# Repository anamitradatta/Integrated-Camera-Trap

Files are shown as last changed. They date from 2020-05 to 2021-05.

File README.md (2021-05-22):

Integrated-Camera-Trap

Senior Design Project 2020 Team 15

Members: <br />
Anamitra Datta  <br />
Max Haimowitz <br />
Xiaoyang Pan <br />
Minting Chen <br />

Advisors: <br />
Professor Duncan Irschick: (https://www.bio.umass.edu/biology/about/directories/faculty/duncan-j-irschick) <br />
Professor David Schmidt: (https://mie.umass.edu/faculty/david-schmidt) <br />
Professor Marco Duarte (ECE SDP Advisor) : (https://ece.umass.edu/faculty/marco-duarte) <br />

http://www.ecs.umass.edu/ece/sdp/sdp20/team15/

Network of Raspberry Pis connected with Camera Modules to take synchronized pictures via WIFI using Message Query Telemetry Transport (MQTT) (Mosquitto) triggered by motion sensors

If you need access to this repository, contact me at my email address: anamitradatta@gmail.com and cc Professor Duncan 
Irschick and/or Professor David Schmidt and ask them to grant permission. Please provide your github username as well.

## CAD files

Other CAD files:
3d_models/SensorShell.f3d
3d_models/enclosure.f3d

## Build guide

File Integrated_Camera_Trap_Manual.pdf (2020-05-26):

# Integrated Camera Trap

## Installation Guide and Instruction Manual

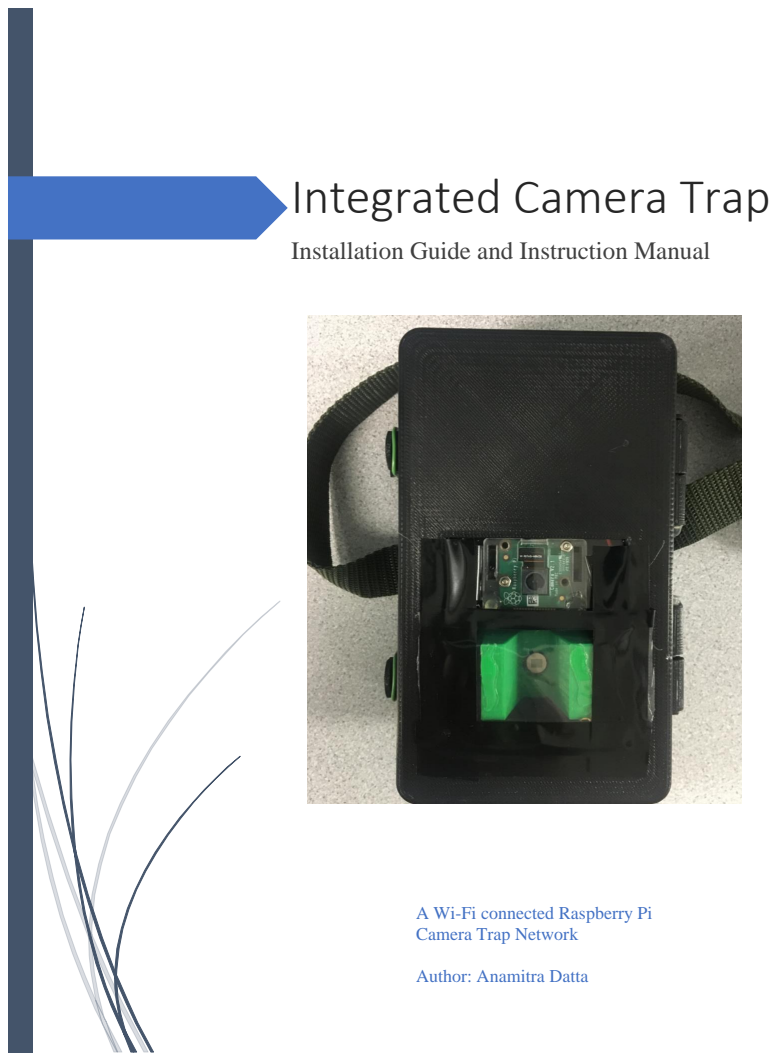
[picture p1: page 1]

A Wi-Fi connected Raspberry Pi
Camera Trap Network

Author: Anamitra Datta

## Contents

## 1. Introduction

### a. Background

Camera Traps have been used by biologists and wildlife researchers to observe animals through the use of photos and 3D modeling rather than dangerous and disruptive physical techniques such as tranquilization and traps which can disturb and harm animals. However, the problem with current camera traps is that they are neither connected nor synchronized. This becomes an issue when photo sets generated by the camera traps are used for 3D modeling, resulting in poor, disconnected, and fragmented models as a result of desynchronized photos. Our system aims to improve this issue by connecting the camera traps through Wi-Fi and ensuring photo capturing synchronization through timed messages sent over Wi-Fi, telling each camera trap when to take a photo.

### b. Network Design

Our network uses a master-slave paradigm in which one “master”/main device sends messages to all the of the “slave”/secondary devices when to take a photo. The figure below shows how to the system is set up.

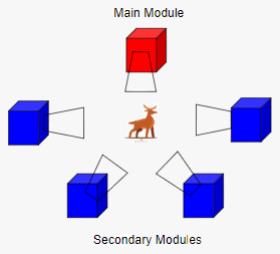
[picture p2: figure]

The camera traps should be arranged in a circle around a single point/area of focus where an animal is likely to appear. There should only be one “master” device in the network and the rest of the devices should be “slave” devices.

### c. Hardware

Our camera trap runs on a Raspberry Pi Zero WH (Wireless with Headers) as shown below

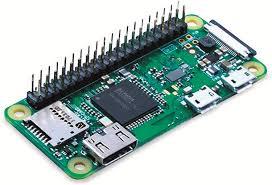
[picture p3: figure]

A Raspberry Pi is a small single-board computer. This board functions like a normal computer in which you can run software and even install physical components.

More information about the Raspberry Pi can be found on the official Raspberry Pi website: https://www.raspberrypi.org/

### d. Software and Networking

The system runs on Wi-Fi through the use of either a router or a wireless access point that can be set up using a Raspberry Pi.

The messages sent within the system are through the use of MQTT (Message Queuing Telemetry Transport). A “broker” is used to send or “publish” messages to all devices listening or “subscribing” to an MQTT “topic” or channel within a network. The broker/publisher and subscribers can be set up using Mosquitto, a free, open-source software for MQTT. More information about Mosquitto can be found on the official Mosquitto website: https://mosquitto.org/

The code running the camera synchronization and photo capturing script is written in Python. More information about Python can be found on the official Python website: https://www.python.org/

## 2. Unix

### a. Introduction to Unix

The Raspbian OS that the Raspberry Pi uses is part of the Linux/Unix OS family. Knowledge of this OS and how to use it is necessary for this system. This chapter covers all of the basic topics of the Raspbian OS that are needed for this system to function.

### b. Basic commands

The main way people use a Linux/Unix based operating system is through the command line or terminal. In this section we will cover some basic command line functions so you can get used to working in a Linux/Unix environment. Documentation for Linux commands: http://man7.org/linux/man-pages/index.html . Also type “man <command name>” to get information about a particular Linux command.

i. ls
This lists the contents of the directory you are currently in or the directory you specify

ii. cd
This changes the directory you are currently in. If you want to change to a different directory type this command.

iii. mv
Move a file to a destination directory optionally with a different name and delete the old file.

iv. cp
Copy a file to a destination directory optionally with a different name and preserve the old file.
v. rm
Remove a file or directory

vi. mkdir
Make a directory

vii. pwd
Print the current working directory you are in.

Permissions
Permissions control who can read, write, or execute a file or directory. Root has the highest permission in Unix subsystems. To be a root user, you must in the sudoers list in the operating system (you are automatically in it by default on Raspbian). Next you must type in the command “sudo su” to change to the root user. Sometimes you need a password to become the root user. If you ever need root privilege to execute a command type “sudo” before your whole command.

viii. chmod
Change read, write, and execute permissions of a file.

ix. chown
Change who owns a file or directory.

### c. Processes

Programs and other software that run on an Operating System are referred to as processes. When you execute a program or command, it will run as a process. Here are commands that deal with processes:

i. ps
Lets you view all process running on the operating system. Alternatives include top or htop

ii. kill
Kill or stop a process from executing

### d. Power

i. reboot
Restart/reboot the Pi

ii. poweroff
Shutdown the Pi.

### e. Startup services

In our system, we have programs that must start up immediately when the Raspberry Pi boots up. There are many different ways to start programs up on boot.

i. rc.local
This is a file that starts just after all normal services have been started. This is just a bash script file which can run shell commands or any software commands. It is located in the /etc/ folder.

For example, we can start the mobile app with the command “python -u ct_mobile_server.py > output.txt 2>error.txt </dev/null &” and put it in the rc.local file. This starts the mobile app server as a background process and writes the output and errors to separate files on startup, as long as it connected to a proper Wi-Fi network.

ii. Systemd
https://www.freedesktop.org/wiki/Software/systemd/

https://www.raspberrypi-spy.co.uk/2015/10/how-to-autorun-a-python-script-on-boot-using-systemd/ (https://www.raspberrypi-spy.co.uk/2015/10/how-to-autorun-a-python-script-on-boot-using-systemd/)

Systemd is a service manager which can control which process can run on startup and run them as a service file.

To set a python program (for example, the CT slave program) as a systemd service, write the service file with the command “sudo nano /lib/systemd/ctslave.service”

Add in the following to the ctslave.service file and save it:
[Unit]
Description=Camera Trap Slave Service After=network-online.target Wants=network-online.target

[Service]
Type=idle
User=pi
ExecStart=python -u /home/pi/ct_client_slave.py

[Install]
WantedBy=network-online.target

Give the file root permissions with the command “sudo chmod 777 /lib/systemd/ctslave.service” Type in the commands “sudo systemctl daemon-reload” and “sudo systemctl enable ctslave.service” and then reboot the pi. The program should successfully run on startup. You can check using “sudo systemctl status ctslave.service” . You can check the output of the service using journalctl.

You can start the mobile app server or the slave or master CT programs using systemd

iii. Cron
http://man7.org/linux/man-pages/man5/crontab.5.html

Cron is a software utility which provides a time based job scheduler. You can start scripts or programs at specific times. Here is a guide on how to write a crontab to automatically start a program or command: https://help.ubuntu.com/community/CronHowto

## 3. Installation and Setup

### Camera Trap Raspberry Pi a. Supplies

The supplies we used are listed below, but you can use any components that are similar and fit within the enclosure

PIR Motion Sensor | Adafruit | HC-SR501 | $10.00
Raspberry Pi Zero WH | Raspberry Pi | Zero WH | $14.00
Raspberry Pi Camera Module V2 (8 Megapixel,1080p) | Raspberry Pi | V2, 8MP, 1080p | ~$25.00

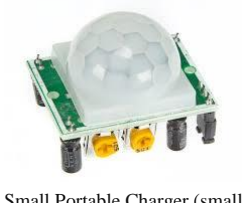
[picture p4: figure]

Portable Charger | Sethruki | 20000mAh, T-28 | ~$25.00
Raspberry Pi Zero WH (Wireless With Headers) | HC-SR501 PIR Motion Sensor

Small Portable Charger (small

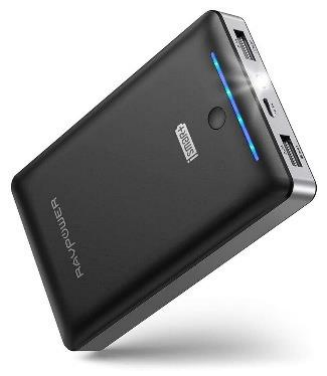
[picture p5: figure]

enough to fit in enclosure)

MicroSD card (16-32 GB) and SD Card Adapter | Micro USB to USB adapter or

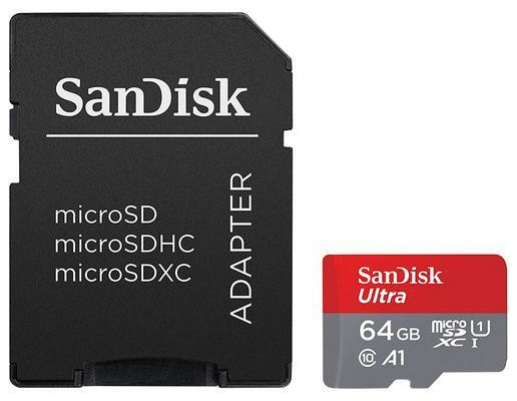
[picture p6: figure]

| USB Hub (for USB Wireless Mouse and Keyboard)

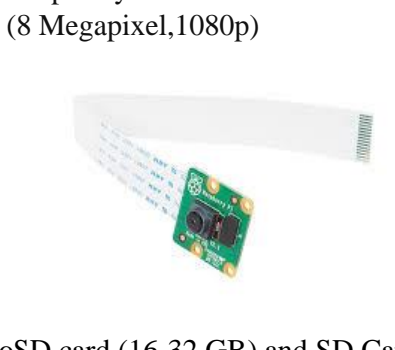
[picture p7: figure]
(8 Megapixel,1080p)

Raspberry Pi Camera Module V2

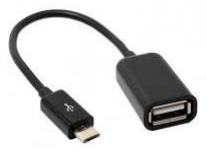
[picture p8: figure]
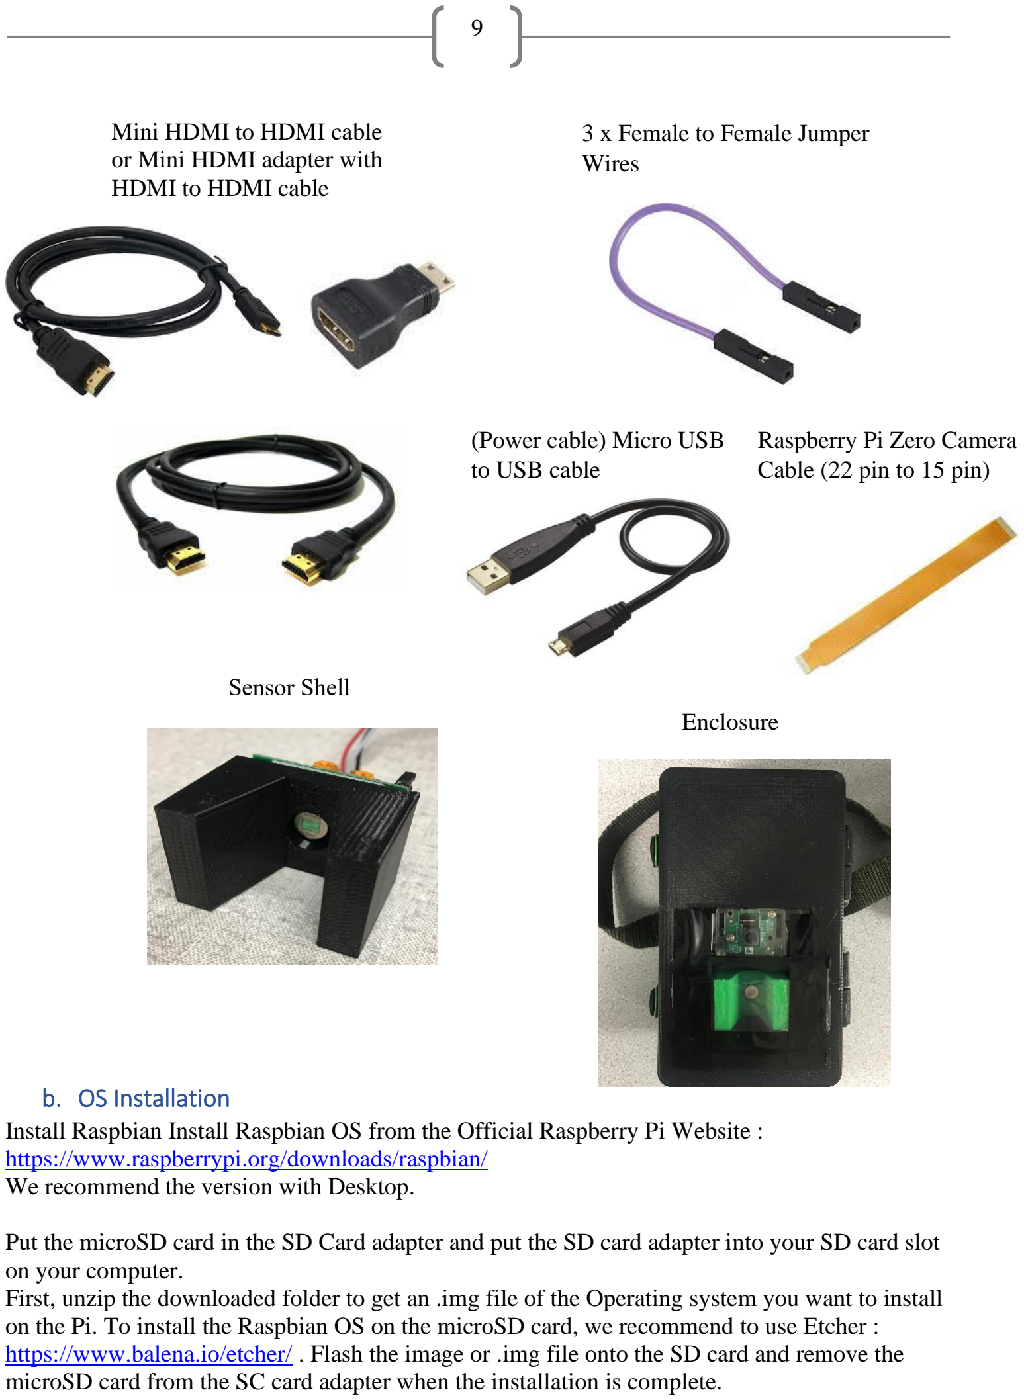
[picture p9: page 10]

### b. OS Installation

Install Raspbian Install Raspbian OS from the Official Raspberry Pi Website : https://www.raspberrypi.org/downloads/raspbian/
We recommend the version with Desktop.

Put the microSD card in the SD Card adapter and put the SD card adapter into your SD card slot on your computer.
First, unzip the downloaded folder to get an .img file of the Operating system you want to install on the Pi. To install the Raspbian OS on the microSD card, we recommend to use Etcher : https://www.balena.io/etcher/ . Flash the image or .img file onto the SD card and remove the microSD card from the SC card adapter when the installation is complete.

Mini HDMI to HDMI cable
or Mini HDMI adapter with
HDMI to HDMI cable

3 x Female to Female Jumper Wires

(Power cable) Micro USB
to USB cable

Raspberry Pi Zero Camera
Cable (22 pin to 15 pin)

Sensor Shell
Enclosure

### c. Setting up the Raspberry Pi

i. Add components and start up OS

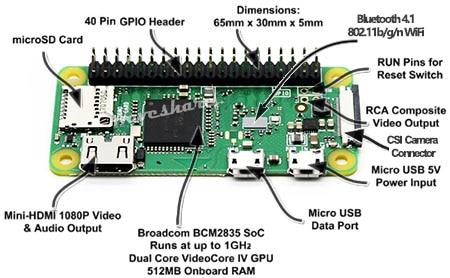
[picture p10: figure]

Place the microSD card into the microSD card slot on the Raspberry Pi

Put the 22 pin side of the wire on the bottom slot of the camera module and the 15 pin side of the wire in the Raspberry Pi CSI camera connector on the end of the Pi. Make sure the dark or white part of the wire faces up. Make sure the camera is attached as shown below.

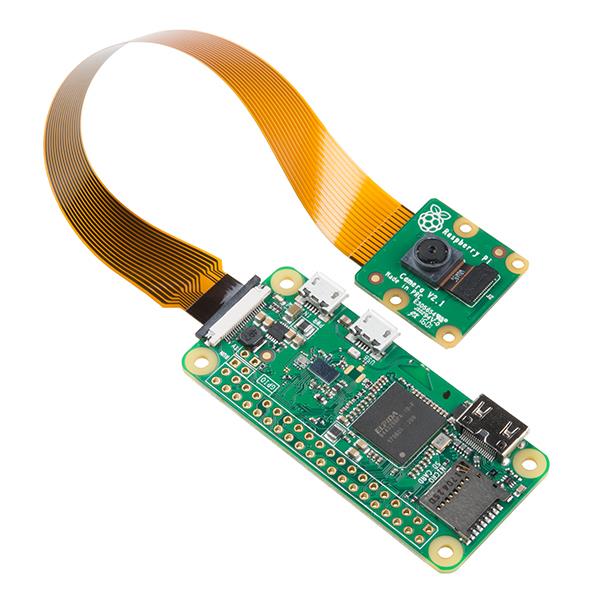
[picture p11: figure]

Attach the PIR Sensor with the female to female jumper wire cables to the Raspberry Pi Zero as shown below. Make sure the pins match with each other.

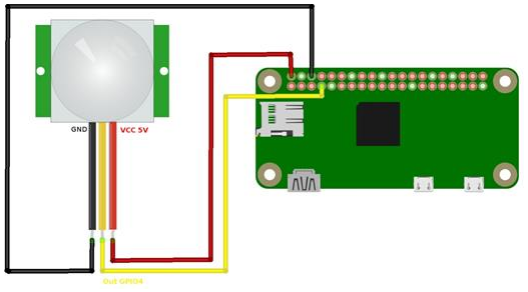
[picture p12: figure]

Plug in the Micro USB to USB adapter/hub in the Micro USB data port and attach your wireless USB Mouse and Keyboard

Plug in the mini HDMI to HDMI cable or mini HDMI adapter to the mini HDMI port and attach an HDMI cable to a computer Desktop monitor

Finally, plug in the power cable to the Pi in the micro USB power input port and attach it to a power outlet or a small portable charger

A few Raspberry Pi logos, a rainbow-colored screen, and maybe some startup scripts should appear. This means that the Raspbian OS is booting up and you had successfully installed the OS on the Pi. If it does not work, make sure you have followed all of the steps, make sure the Pi works properly and make sure the image is installed on the microSD card correctly and make sure the microSD card is working properly.

The default username is "pi" and the default password is "raspberry"

You can change the password for user "pi" if you want, but it is not necessary. Follow these instructions: https://www.raspberrypi.org/documentation/linux/usage/users.md

If you want to change the password, use the command “passwd” or type in “sudo raspi-config” and select option 1. Change User Password

If you are using a Headless Raspbian OS without a GUI/Desktop, edit XKBLAYOUT line in /etc/default/keyboard from "gb" to "us" using nano with the command “sudo nano /etc/default/keyboard”

ii. Wi-Fi Setup
Follow these instructions to set up Wi-Fi depending on your setup: https://www.raspberrypi.org/documentation/configuration/wireless/

You need to connect to the Internet for the next few steps.

Desktop:

In the upper right corner, there should be network icon that looks like this:

Click it, and click on the Wi-Fi network you want to connect to and type in the password of the Wi-Fi network. When the icon becomes fully blue, you should be fully connected to Wi-Fi

Command Line:

Type in “sudo raspi-config” and select 2. Network Options and then 2.Wi-Fi. Type in the ssid of the network you want to connect to and its password. After that, reboot the Pi and you should be connected to the Wi-Fi network you specified.

Or

You can edit the /etc/wpa_supplicant/wpa_supplicant.conf file to add this line at the bottom:

network={
| ssid="<name of Wifi Network>" psk="<Password for that Wifi Network>"

}

Then reboot the Pi and should you be able to connect to the Wi-Fi network specified.

Depending on your Wi-Fi network configurations, you might need to add extra parameters to connect, see the documentation for more details,
http://w1.fi/cgit/hostap/plain/wpa_supplicant/wpa_supplicant.conf -
Documentation for wpa_supplicant.conf

To set up a static IP address for the Raspberry Pi, edit the dhcpcd.conf file using the command “sudo nano /etc/dhcpcd.conf” and add the following line with the ip address you want to set the Pi to specifically (24 is the subnet mask)

static ip_address=192.168.0.1/24 iii. Installation software and enabling interfaces
When you are connected to the internet, type in the following in the command line and type "y" when asked to install the following:
sudo apt-get update
sudo apt-get upgrade
sudo apt-get install mosquitto mosquitto-clients sudo apt-get install python-pip
sudo pip install paho-mqtt
sudo apt-get install ftpd
sudo pip install gpiozero
sudo pip install picamera
sudo apt-get install fbi
sudo apt-get install sshpass
sudo apt-get install python-paramiko

SSH (protocol to log into Pi remotely) is disabled by default, we need to enable SSH to enable SSH:

1. type "sudo raspi-config" in the command line
2. Select 5.Interfacing Options
3. Select P2 SSH
4. reboot the pi by typing "sudo reboot" in the command line

SSH in now enabled and you can SSH into the Pi from any device using a software client or through command line (https://man.openbsd.org/ssh)

FTP or SCP files from https://github.com/anamitradatta/Integrated-Camera-Trap for
each Pi. We recommend an FTP or SCP client:

WinSCP (Windows only)
Filezilla
Cyberduck

The camera is disabled by default, we need to enable Camera to enable camera:
1. type "sudo raspi-config" in the command line
2. Select 5.Interfacing Options
3. Select P1 Camera
4. reboot the pi by typing "sudo reboot" in the command line

The Camera is now enabled and working
If you want to test the camera, run test_camera.py to see if it can take a photo "test_photo.jpg"

In the main source code folder, type in the command "sudo chmod 777 ./*" and "sudo chown pi ./*" to run all files as user pi without root permissions

Make a directory called cameraTrapPhotos in the /home/pi directory.

Python should be pre-installed on Raspbian OS. Make sure python or python3 is installed on your OS by typing in "python --version", if returns nothing, then you need to install python for Linux https://www.python.org/downloads/source/

### Access Point Raspberry Pi

In our system, we will be using and setting up a Raspberry Pi Zero W to act as an access point or router in our system so we do not need the use of a physical router or switch in our network.

i. Supplies
Raspberry Pi Zero W or WH | Small Portable Charger (small enough to fit in enclosure)

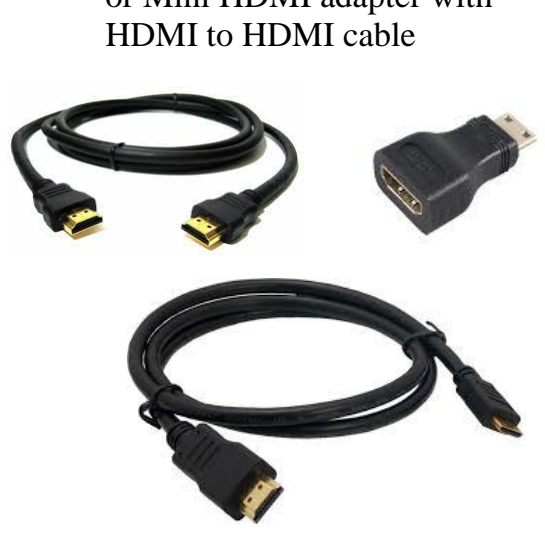
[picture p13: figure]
HDMI to HDMI cable

MicroSD card (16-32 GB) and SD Card Adapter

Micro USB to USB adapter or USB Hub (for USB Wireless
Mouse and Keyboard)

Mini HDMI to HDMI cable
or Mini HDMI adapter with

ii. Setup and installation

Set up the Raspbian Operation System with Desktop as you did before for the camera trap Raspberry Pi and connect to the Internet.

We will now set up the Raspberry Pi as an access point (AP).

Here is a guide to setting up the Pi as an access point, which we will cover in this section: https://learn.sparkfun.com/tutorials/setting-up-a-raspberry-pi-3-as-an-access-point/all
All files are also available on the Github if needed for reference under the AP_Files folder.

We will need to use nano (an inbuilt text editor) to change some configuration files. To save a file in nano, press ctrl + o and then ctrl + x to exit the file. Nano documentation: https://www.nano-editor.org/docs.php

When you are connected to the internet, type in the following in the command line and type "y" when asked to install the following:
sudo apt-get update
sudo apt-get upgrade
sudo apt-get install ftpd
sudo apt-get install hostapd
sudo apt-get install dnsmasq

First make a backup of all files we will be editing with the commands: sudo cp /etc/dhcpcd.conf /etc/dhcpcd.conf.backup
sudo cp /etc/network/interfaces /etc/network/interfaces.backup
sudo cp /etc/hostapd/hostapd.conf /etc/hostapd/hostapd.conf.backup
sudo cp /etc/dnsmasq.conf /etc/dnsmasq.conf.backup

We are going to set a static IP address on our AP Raspberry Pi. Edit the dhcpcd.conf file with the command “sudo nano /etc/dhcpcd.conf”. Go to the bottom of the file and add the following line and save the file:
denyinterfaces wlan0

Next, edit the interfaces file with the command “sudo nano /etc/network/interfaces” Go to the bottom of the file and add the following and save the file:
auto lo
iface lo inet loopback

auto eth0
iface eth0 inet dhcp

allow-hotplug wlan0
iface wlan0 inet static
address 192.168.5.1
netmask 255.255.255.0
network 192.168.5.0
broadcast 192.168.5.255

Next we have to configure hostapd, which allows the Raspberry Pi’s WiFi chip to broadcast an SSID and allow Wi-Fi connections on a certain channel
Edit the hostapd.conf file with the command “sudo nano /etc/hostapd/hostapd.conf”

Enter the following into the file and save the file:
interface=wlan0
ssid=CTWifi
hw_mode=g
channel=7
ieee80211n=1
wmm_enabled=1
ht_capab=[HT40][SHORT-GI-20][DSSS_CCK-40] macaddr_acl=0
auth_algs=1
ignore_broadcast_ssid=0
wpa=2
wpa_key_mgmt=WPA-PSK
wpa_passphrase=cameratrap
rsn_pairwise=CCMP
wpa_pairwise=TKIP

Feel free to change the ssid and wpa_passphrase to whatever you like. These are your Wi-Fi name and the Wi-Fi password. In our example, we use CTWifi as the SSID and cameratrap as the password for the CTWifi network.

Edit the hostapd startup script with the command “sudo nano /etc/default/hostapd”

Find the line where it says #DAEMON_CONF=”” and replace it with: DAEMON_CONF=”/etc/hostapd/hostapd.conf”

Next we have to set up the DHCP server which hands out IP addresses to different devices connected to the network.

Edit the dnsmasq.conf file with the command “sudo nano /etc/dnsmasq.conf”

Add the following to the bottom of the file and save it:
interface=wlan0
listen-address=192.168.5.1
bind-interfaces
server=8.8.8.8
domain-needed
bogus-priv
dhcp-range=192.168.5.100,192.168.5.200,24h

You can also assign static IPs to specific devices in dnsmasq.conf, for example if the device with MAC address 00:00:5e:00:53:42 was designated as the slave#2, we could set up a static IP for that device by adding the following line to the dnsmasq.conf file:

dhcp-host=00:00:5e:00:53:42,ctslave2,192.168.5.102

This will have the DNS server assign a name to this device and give a static IP of 192.168.5.102 as well. You can optionally do this for the devices, so you can refer the device as a name rather than an IP address.

You can edit the dhcp range from anything from 192.168.5.2 to 192.168.5.254. But remember, the AP Pi uses 192.168.5.1, so do not assign a Pi with that IP address.
Now reboot your Pi. You can test if the Wi-Fi access point works from your computer. You can connect to it by typing in the password you have in the hostapd.conf file.

You have now successfully built the Access Point Pi for the camera trap network.

You can connect the other Pis to the AP network by either using the WiFi icon/raspi-config and inputting the password or editing the wpa_supplicant.conf file with the ssid and password you chose for the AP.

### d. How to run the code

In the main source code folder, type in the command "sudo chmod 777 ./*" and "sudo chown pi ./*" to run all files as user pi without root permissions. Make a directory called cameraTrapPhotos in the /home/pi directory

Python should be pre-installed on Raspbian OS. Make sure python or python3 is installed on your OS by typing in "python --version", if returns nothing, then you need to install python for Linux https://www.python.org/downloads/source/. Make whatever changes to parameters are needed in the code. Type "python <name of python file>" to run the code

You must turn on the master Pi before the slave Pis and make sure they are all running on the same network. Run the slave Pis first with the command “python ct_client_slave.py”, and then when all the slave Pis are running, run the Master code with the command “python ct_publish_master.py”.

Either run the single sensor photo triggering or the multiple sensor photo triggering. Do not run both at the same time.

There should only be one master running and multiple slaves running. Make sure the slave Pi programs have the IP address of the master Pi in their code and are connected to the network.

In this section, we will show how to run the single sensor camera trap program.

First run the slave Pis. Be sure the master Pi is on and has the software installed. The message below should appear on the slave Pis if everything is set correctly.

When all the slave devices are on and connected, run the master pi. This message should appear.

After a few seconds, the master Pi will wait for the motion sensor to be triggered. When the motion sensor senses something, it will start the photo session.

The slave device will receive a message when motion has been detected from the master Pi and will also take a photo and send it to the master device as shown in the screenshot below. Here we only have one slave device running.

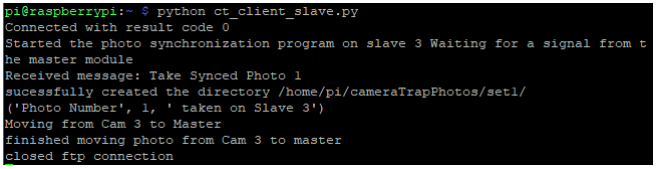
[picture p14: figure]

On the master Pi, in the cameraTrapPhotos directory, you should have some photo sets with photos from all cameras running as shown below

The multiple sensor camera trap program runs the same way.

First, make sure the master device is on and run the slave Pis and the message below should appear if everything is set correctly.

Then run the master Pi when all the slave devices have started running. The message below should appear

After a few minutes, the master device should get a response from all slave devices as shown below. Here we only have one slave device running.

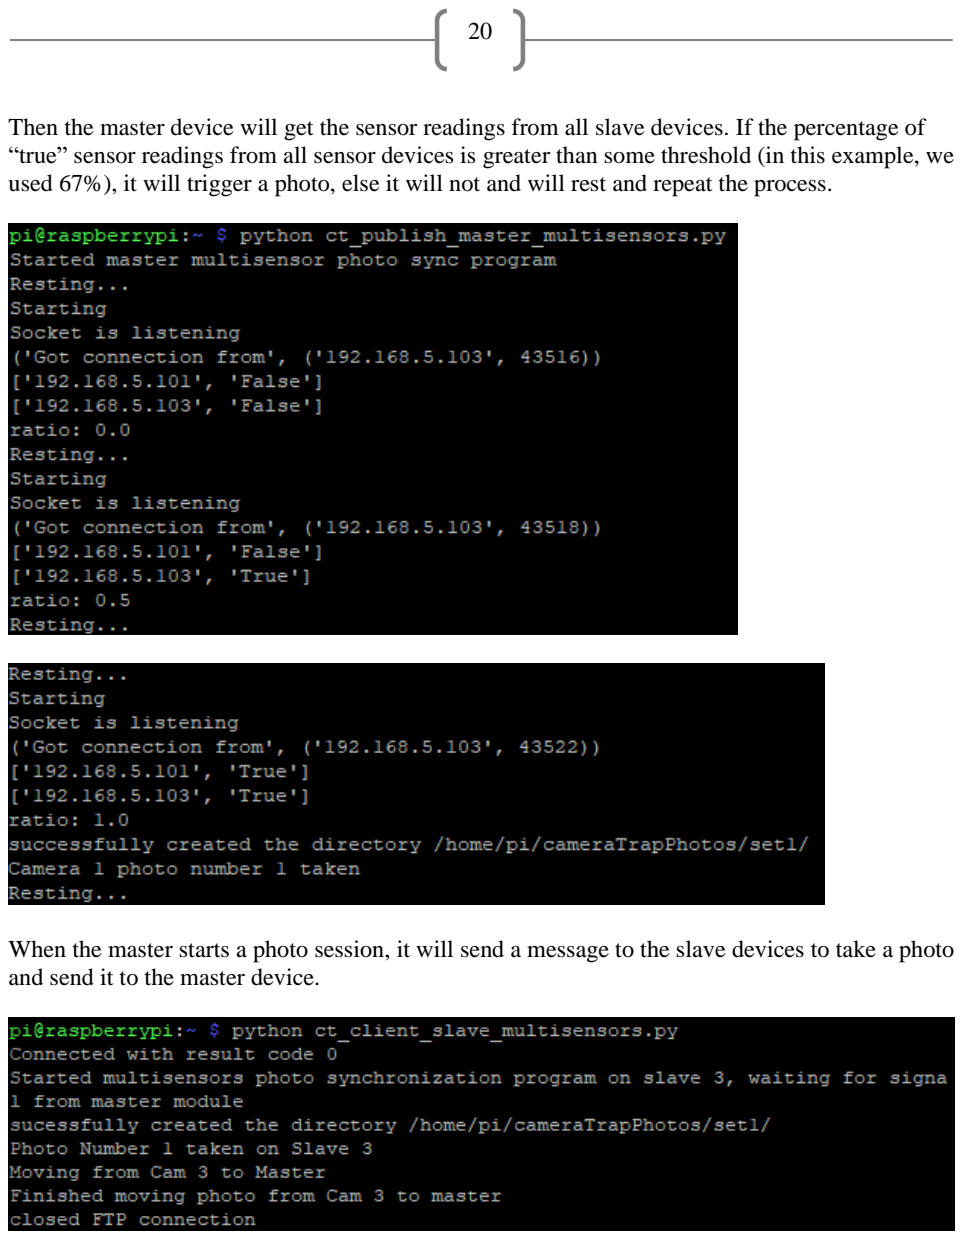
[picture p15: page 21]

Then the master device will get the sensor readings from all slave devices. If the percentage of “true” sensor readings from all sensor devices is greater than some threshold (in this example, we used 67%), it will trigger a photo, else it will not and will rest and repeat the process.

When the master starts a photo session, it will send a message to the slave devices to take a photo and send it to the master device.

### e. Setting up mobile app

To set up the mobile app, we first need to install Android Studio: https://developer.android.com/studio

Download the mobile app folder from Github

In Android Studio, go to the “File” tab, and select “import project”. Select the mobile app folder you downloaded.

Plug in your Android phone via USB into your computer. To download the app onto your phone, you must go into your phone’s settings and enable USB debugging.

Run the app by clicking on the run button or go to the “Run” tab and click “Run App”
The app should be installed on your phone

On your phone, you must also install an FTP server app, we recommend this app: https://play.google.com/store/apps/details?id=com.medhaapps.wififtpserver&hl=en_US

Make sure that the port number is 2221 and the username and password are set to the ones in the code. The default using our recommended app is username:android, password:android . Start the FTP server on. Make sure the settings are similar to the one shown below

### f. Setting up mobile server

Download the ct_mobile_server.py from Github. Make sure the IP address, client port, and the username and password for the FTP server are the same as the one you are running on the phone.

Run the mobile server code on the Master Pi using the command “python3 ct_mobile_server.py”. Make sure you are connected to the same network the master Pi is on. Make sure the host IP in the code is correctly set to the IP address of the Master Pi. This message should appear on the Pi.

Run the FTP server and mobile app on the phone. Type in the IP address of the Master Pi and the port for the mobile server (default port = 8888) as shown below. You should see a connected text on the mobile app on the next page if you successfully set it up.

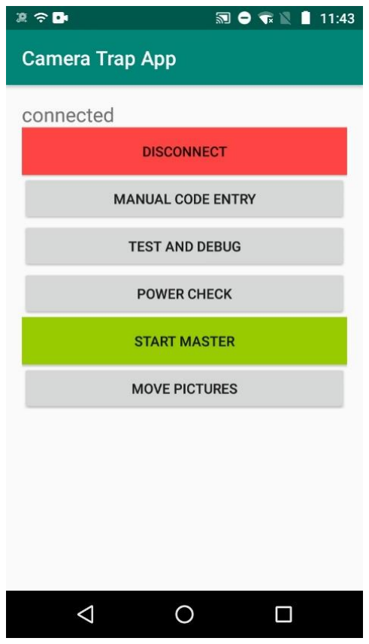
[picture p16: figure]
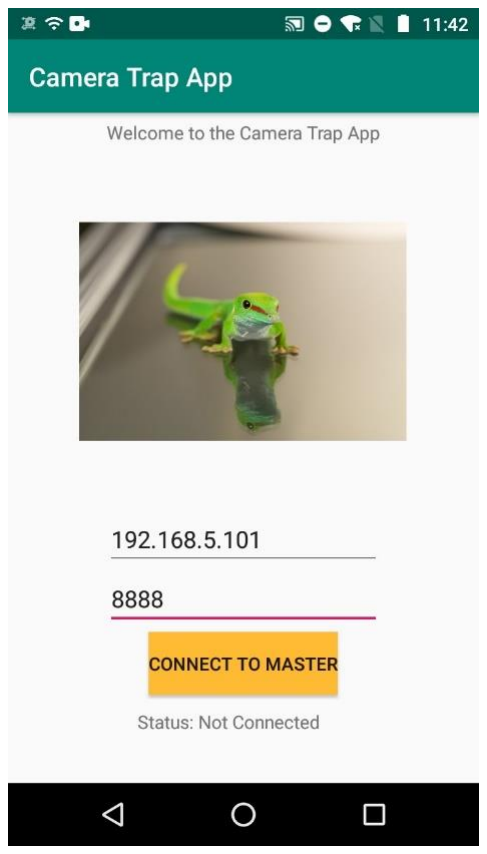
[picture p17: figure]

The phone should be connected now and a message will appear on the master Pi as shown below if successful. From there, as long as the mobile server is running on the master Pi, you can do many options, including downloading the photos onto an SD on your phone. For this, make sure the FTP server is running on your phone. If you are disconnected from the socket connection and cannot connect to the Pi through the phone, restart both the mobile app and the mobile server on the Pi.

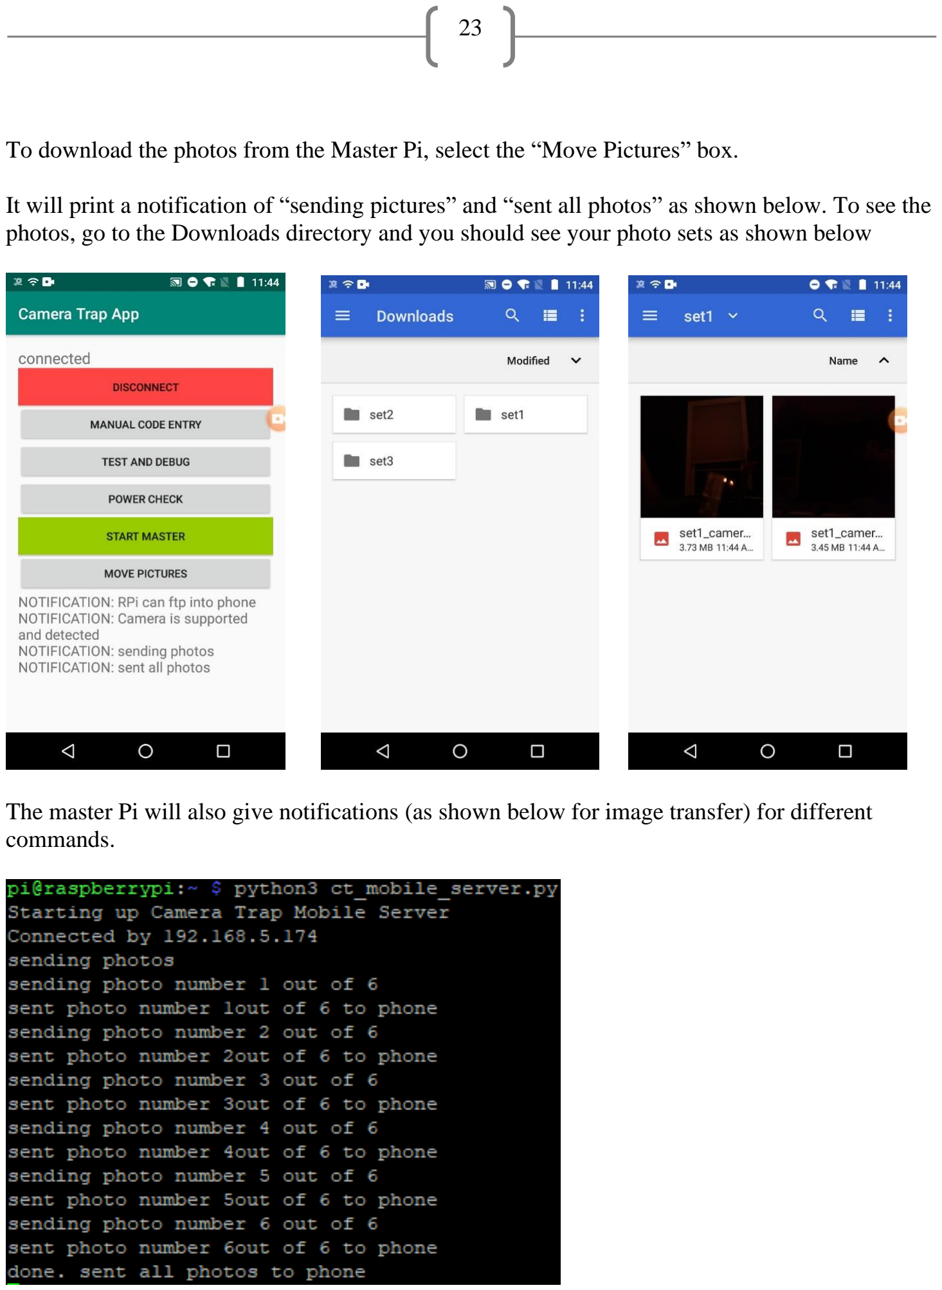
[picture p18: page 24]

To download the photos from the Master Pi, select the “Move Pictures” box.

It will print a notification of “sending pictures” and “sent all photos” as shown below. To see the photos, go to the Downloads directory and you should see your photo sets as shown below

The master Pi will also give notifications (as shown below for image transfer) for different commands.

### g. Setting up RTC (Real time clock)

Optionally, you can install an RTC (real time clock) on the Access Point Raspberry Pi. The Pi does not have a hardware clock to keep track of time. It has a software clock synchronized with an NTP server over the Internet to keep the time. In this section, we will add a hardware clock which has a timer to the Pi. This will be helpful for maintaining time synchronization within the system.

Here is a guide to setting up an RTC on the Raspberry Pi. https://learn.adafruit.com/adding-a-real-time-clock-to-raspberry-pi (https://learn.adafruit.com/adding-a-real-time-clock-to-raspberry-pi)

Make sure you are connected to the Internet. Set the time of the Pi synced with the NTP server by typing the command “sudo raspi-config”, then select 4. Localisation Options then I2. Change Timezone, and select the time zone you are currently in. This will set the Pi’s time to the time controlled by the NTP server for the time zone you selected.

We recommend using the PCF8523 RTC (https://www.adafruit.com/product/3386), but feel free to use any RTC of your choosing

Put the RTC on the GPIO pins on the end near the SD Card like in the figure below

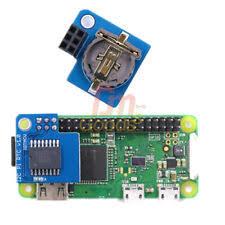
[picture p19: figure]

First ,enable I2C by typing “sudo raspi-config”, then 5. Interfacing Options, then P5. I2C, then reboot the Pi.

Run the command “sudo apt-get install python-smbus i2c-tools”

Then, type “sudo i2cdetect -y 1”. You should see ID # 68 appear, which is the address of the RTC

Next, edit the /boot/config.txt file with the command “sudo nano /boot/config.txt”

Add the line:
dtoverlay=i2c-rtc, pcf8523

To the end of the file and save it. Change the RTC name depending on which one you use.

Reboot the Pi and then run “sudo i2cdetect -y 1” again and you should see UU where it showed #68 before

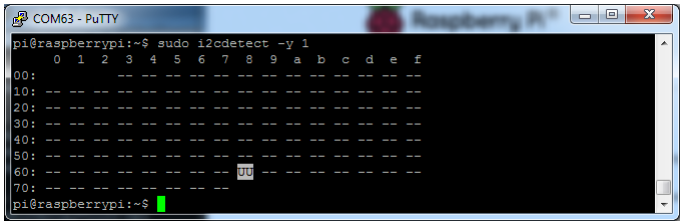
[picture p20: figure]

Disable the software clock by running the commands: sudo apt-get -y remove fake-hwclock
sudo update-rc.d -f fake-hwclock remove
sudo systemctl disable fake-hwclock

Now, edit the file /lib/udev/hwclock-set by running the command “sudo nano /lib/udev/hwclock-set”

Comment out these lines by putting a # sign in front of them
if [ -e /run/systemd/system ] ; then
exit 0
fi

Your file should look like this:

Also comment out these two lines: /sbin/hwclock --rtc=$dev –systz –badyear /sbin/hwclock –rtc=$dev –systz

Then reboot the Pi again. To read the time from the RTC use the command “sudo hwclock -D -r”. The current time on the hardware clock is invalid. To set the time, first run the command “date” to verify the time is correct. Then run the command “sudo hwclock -w” to write the time to the RTC. Then “sudo hwclock -r” to read the time from the RTC. If the time from the RTC is correctly synced, you have successfully set up the RTC.

You can sync the times of all of the Pis in the network through the Access Point Pi which has the RTC using the timesyncssh.sh file in the AP_Files folder. The access point Pi uses the script’s awk utility to get the IP addresses of all Pis in the network and then ssh individually into each Pi and set the time from its RTC onto each Pi’s time.

### h. Setting up the enclosure

i. Materials for enclosure

Enclosure (https://a360.co/2zXcFQ9)

Sensor Shell (https://a360.co/3bZRaMz)

Lexan Sheet (https://tinyurl.com/y7o8oo8y)

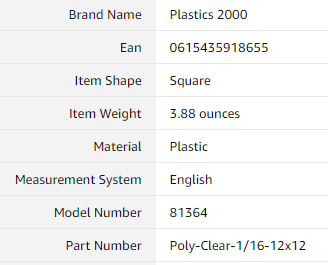
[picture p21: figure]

4x 2.5M screws

8x 2M screws

Rubber O-Ring

Hot glue gun

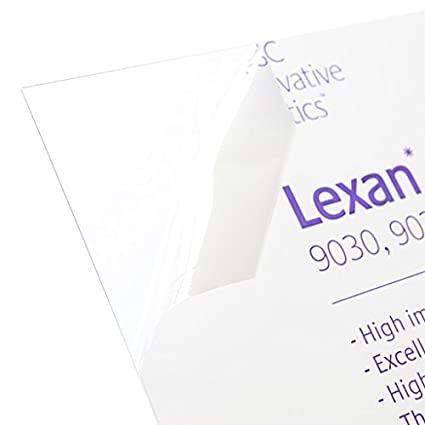
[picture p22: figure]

ii. Steps to set up enclosure

1. View and download the 3D models. Also download Autodesk Fusion 360 to edit the 3D models if needed.
2. 3D-print the enclosure in UMass M5 or UMass library. The technicians in the printing lab will help you set up the parameters
3. Use the M2.5 screws to mount the Raspberry Pi on the board

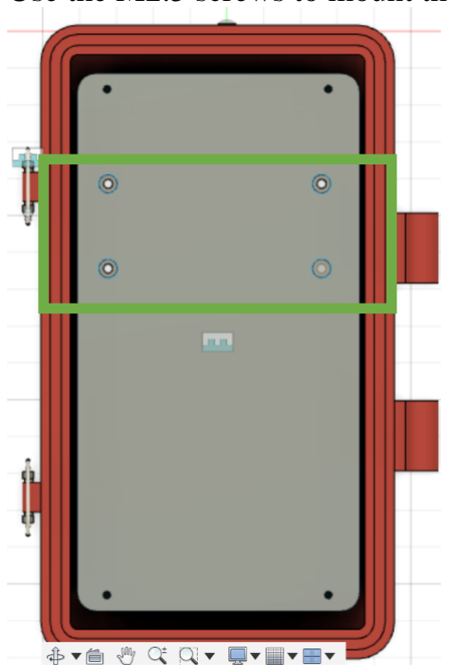
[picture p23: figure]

4. Connect the USB cable, camera, and PIR sensor to the pi
5. Cut the Lexan sheet to a square with length of 6.5cm and use hot glue to seal it on the window of the lid
6. Use the M2 screw to mount the sensor to the sensor shell

7. Then attach the camera and the sensor to the window using hot glue. They should be in a column. Camera is placed on top of the sensor.
8. Then mount the board to the lid using M2 screws
9. Use a rubber O-ring to fill in the gap on the bottom part of the enclosure.

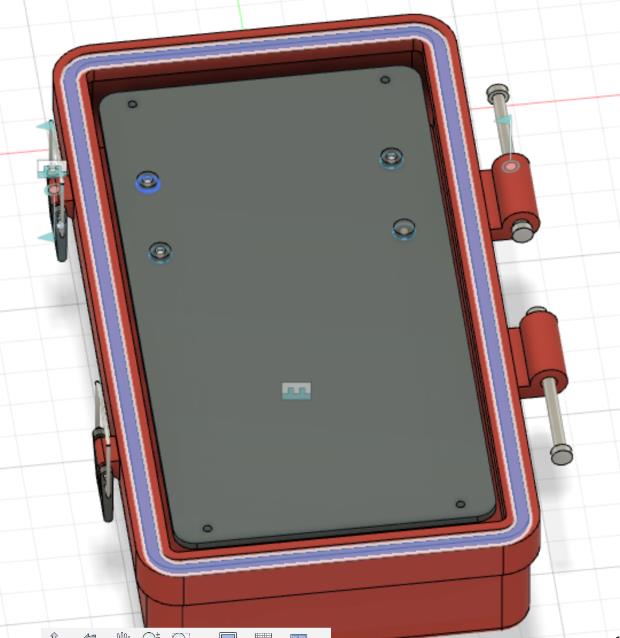
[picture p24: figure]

10. Connect the USB cable to a power bank, now you should see a yellow LED lights up on the raspberry pi.

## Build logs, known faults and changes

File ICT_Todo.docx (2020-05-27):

Things that still need to be done/ things our group could not complete in time:

Camera Trap System:

- Combine router and master so that the master device can serve as the router for the network so we can have one less device in the network. This device needs to be a Raspberry Pi Zero W.
- Make the router a Raspberry Pi Zero W
- Provide a clean, organized way to assign device numbers to each Pi, so far, we need to hardcode it into the code (assign it manually in the code, which is complicated and can be messy and disorganized)
- Provide a way to turn on the whole system without the use of the mobile app, perhaps through a Python or shell script
- Make the system headless, so that we do not need to log into the computer to start the code
- Make the camera trap system codes run as services, so they can be started and stopped cleanly.
- We did not test how long the system runs for, how much power consumption each device takes
- It might be possible to reduce latency between photos/devices by optimizing the code (multithreading, spawning another process), but we could not complete this
- Enclosures still need to be printed out, the one we provided initially is too small. We have updated the 3D model file by increasing the size of the enclosure so it can fit the small battery and the Raspberry Pi Zero W but it still needs to be set up
- Provide a way to change the master device with and without the mobile app. Make sure all devices have the master code and software.
- Provide a way to know that the code is running or not (perhaps with an LED?)
- Provide a proper way to label the devices so they do not mixed up/ cause confusion (put a sticker with a number of the device on the enclosure)
- We did not do testing with proper orientation of the devices/ proper settings (how to set them up so they always take a photo when something is sensed)
- Provide hostnames to all devices in the network through the DNS server
- Reinstall the RTC on the master Pi, and work on the time synchronization script
- Provide a way to make backups of the photos on the devices automatically (through a cron job?)
- We did not do testing of the latency between the photos, but it was mostly consistent (less than 100 ms), try to reduce this if possible
- Provide a way so that the system stops at night, but turns on in daytime – a bit challenging, but you would need electronics/circuits with some software knowledge but this would help a lot in terms of power consumption and system runtime.

Mobile App/ Mobile Server:

- Make the App more user friendly/ clean it up and make it look nice
- Provide a way to a clean way to delete photos from all Pis. (right now when you start the camera trap code, it will automatically delete all photos currently stored in the Pi)
- Provide a way to gracefully start the system
- Provide a way to gracefully stop the system
- Provide a way to view photos on the Pis before downloading them
- Have the mobile app source code start/run an FTP server by itself without the need/use of an external app

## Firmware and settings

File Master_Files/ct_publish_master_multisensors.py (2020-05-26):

import paho.mqtt.publish as publish
from picamera import PiCamera
from time import sleep
import time
from gpiozero import MotionSensor
import socket
import datetime
import os
import shutil
import commands

#Authors:
#Anamitra Datta
#Minting Chen

#Master Publisher code for multiple sensors photo triggering
#Continously and periodically polls all devices in the network to knwo about their sensor values
#If a certain percentage of sensors are true in the network, then motion is detected
#Then, start the photo session process by sending a message to all slave devices to take a photo

print("Started master multisensor photo sync program")

MQTT_SERVER = "localhost" #master Pi IP address
MQTT_PATH = "test" #topic name for MQTT
path = '/home/pi/cameraTrapPhotos/'
pir = MotionSensor(4) #use motion sensor
camera = PiCamera() #use camera
access_rights = 0o777

#create a directory if one does not exist for the camera trap photos
if(os.path.isdir(path)==False):
	os.mkdir(path,access_rights)
#else, remove all photos and photo sets currently in the directory
else:
	for fname in os.listdir(path):
		shutil.rmtree(path+fname)

IPAddr = commands.getoutput("hostname -I") #get Pi's own IP address

threshold = 0.67 #threshold for taking photo, percent of sensors that need to be true to take a photo, configurable
photoNum = 1 #current set/photo number
delay = 30 #amount of time in seconds to rest after a photo session (should be greater than 30 seconds)

#set socket for listening to slave pis
s = socket.socket()
s.settimeout(10) #set timeout for few seconds, enough to read sensor data from all slave Pis
s.bind(('',12345)) #bind the socket to a unused undesignated port

#run continously until terminated by user
while True:
	sensorlist = [] #list of all devices by their ip addresses and their sensor readings
	print("Resting...")
	sleep(delay)
	print("Starting")
	message = "Info"
	publish.single(MQTT_PATH,message,hostname=MQTT_SERVER) #send message get info about slave sensors

    #put sensor state of master pi in sensor list
	if(pir.motion_detected==True):
		sensorlist.append([str(IPAddr).rstrip(),str(True)])
	else:
		sensorlist.append([str(IPAddr).rstrip(),str(False)])

    #listen for incoming connections
	s.listen(5)
	print("Socket is listening")

    #get data from slave pis by listening to socket and parse it and add it to sensor list
	while True:
		try:
			c,addr = s.accept() #accept connections from slave pis
			print('Got connection from', addr)
			receivedInfo = str(c.recv(1024))

            #parse data and add it to the sensor list
			splitInfo = receivedInfo.split()
			receivedIP = splitInfo[0]
			receivedSensor = splitInfo[1]
			sensorlist.append([receivedIP,receivedSensor])
			c.close()

		except socket.timeout:
			break

	#list of all devices and their sensor readings
	for x in sensorlist:
		print(x)

    #calculate percentage of sensors that show true
	numSensors = float(0)
	numTrue = float(0)
	for i, element in enumerate(sensorlist):
		numSensors = numSensors + 1
		if element[1] == "True":
			numTrue = numTrue + 1
	ratio = numTrue/numSensors
	print("ratio: " + str(ratio))

    #if ratio is above the threshold, start a photo session
	if(ratio>threshold):
		#Send MQTT message to slaves to take photo and start photo
		message = "Take Synced Photo " + str(photoNum)
		publish.single(MQTT_PATH,message,hostname=MQTT_SERVER)
		ctpath = '/home/pi/cameraTrapPhotos/set' + str(photoNum) +  '/'
		access_rights = 0o777 #permissions for directory
        #make directory for current photo session
		try:
			os.mkdir(ctpath,access_rights)
		except OSError:
			print("creation of the directory %s failed" % ctpath)
		else:
			print("successfully created the directory %s" % ctpath)

        #set camera and file parameters
		filename = 'set'+str(photoNum)+'_camera1.jpg'
		camera.resolution=(3280,2464)
		camera.shutter_speed = 30000

		#Take Photo
		camera.capture(ctpath+filename)
		#End of Photo session

		print("Camera 1 photo number "+ str(photoNum) + " taken")
		#go to next photo session
		photoNum = photoNum + 1

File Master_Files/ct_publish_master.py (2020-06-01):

import paho.mqtt.publish as publish
from picamera import PiCamera
from time import sleep
from gpiozero import MotionSensor
import os
import shutil

#Author: Anamitra Datta

#Master Publisher Code for single sensor Photo triggering. 
#When the sensor on the master Pi is activated, it will send a message to all slaves devices via MQTT to take a photo

path = "/home/pi/cameraTrapPhotos/" #photos directory
access_rights = 0o777 #permissions for directory , 777 means everyone can read, write, and execute a file

#create a directory if one does not exist for the camera trap photos
if(os.path.isdir(path)==False):
	os.mkdir(path,access_rights)
#else, remove all photos and photo sets currently in the directory
else:
	for fname in os.listdir(path):
		shutil.rmtree(path+fname)

MQTT_SERVER = "localhost" #master Pi IP address
MQTT_PATH = "test" #topic name for MQTT

camera = PiCamera() #use camera
pir = MotionSensor(4) #use motion sensor
photoNum = 1 #current Photo (set) number
delay = 30 #amount of time in seconds to rest after a photo session (should be greater than 30 seconds)

#runs continously until termination by user
while True:
	#Rests for a few seconds to FTP all photos from slave devices and to prevent multiple photos to be taken in a small time frame
	print("Photo synchroniztion program: master device running")
	print("Resting the program for a few seconds...")
	sleep(delay)
	print("Done resting")
	message = "Motion Not Detected" #initalizing message to send via MQTT
	startdetection = False

    #Wait until motion is detected to start photo session
	while True:
		if pir.motion_detected == False and startdetection == False:
			startdetection = True
		sleep(1)
		print(pir.motion_detected)
		if startdetection== True:
			if pir.motion_detected == True:
				#motion detected, change message to "take photo", send to all slave devices, attach current set number
				message = "Take Synced Photo " + str(photoNum)
				break;

	print("Motion has been detected. Taking camera 1 Photo" + str(photoNum))

	#MQTT, send message to all slaves in network to take a photo
	publish.single(MQTT_PATH, message, hostname=MQTT_SERVER)

	path = '/home/pi/cameraTrapPhotos/set' + str(photoNum) +  '/' #path for photo

    #make a directory for the current session to store photos in 
	try:
		os.mkdir(path,access_rights)
	except OSError:
		print("creation of the directory %s failed" % path)
	else:
		print("successfully created the directory %s" % path)

    #set up photo and camera settings
	filename = 'set'+str(photoNum)+'_camera1.jpg'
	camera.resolution=(3280,2464)
	camera.shutter_speed = 30000

	#Take Photo
	camera.capture(path+filename)

	#End of Photo session
	print("Camera 1 photo number "+ str(photoNum) + " taken")

	#go to next photo session
	photoNum = photoNum + 1

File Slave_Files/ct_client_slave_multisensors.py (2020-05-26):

import paho.mqtt.client as mqtt
from picamera import PiCamera
from time import sleep
import socket
import datetime
from ftplib import FTP
import os
import shutil
import commands
from gpiozero import MotionSensor

#Authors:
#Anamitra Datta
#Minting Chen

#Slave client code for multiple sensor photo triggering
#If message "Info" is received from master pi, send data about the sensor to master Pi
#if message "Take" is received from master pi, take a photo and ftp it to master pi

MQTT_SERVER = "192.168.5.101" #IP adress of master pi
MQTT_PATH = "test" #mqtt topic for CT program

pir=MotionSensor(4) #use motion sensor
camera = PiCamera() #use camera
path = '/home/pi/cameraTrapPhotos/' #directory to store photos on
cameraNum = 3 #device number, needs to be different for each pi
access_rights = 0o777 #permissions for directory

#create a directory if one does not exist for the camera trap photos
if(os.path.isdir(path)==False):
	os.mkdir(path,access_rights)
#else, remove all photos and photo sets  currently in the directory
else:
	for fname in os.listdir(path):
		shutil.rmtree(path+fname)

#method to subscribe to MQTT topic
def on_connect(client, userdata, flags, rc):
	#result code 0 = successful
	print("Connected with result code "+str(rc))
	print ("Started multisensors photo synchronization program on slave " + str(cameraNum) + ", waiting for signal from master module")
    # Subscribing in on_connect() - if we lose the connection and
    # reconnect then subscriptions will be renewed.
	client.subscribe(MQTT_PATH)

# The callback for when a PUBLISH message is received from the server.
def on_message(client, userdata, msg):
	wordlist = (msg.payload).split()

	#send info about IP address and sensor reading
	if(wordlist[0]=="Info"): #send sensor status to main pi for consensus
		IPAddr = commands.getoutput("hostname -I") #ip addres of slave pi

        #set up socket connection with master pi to send sensor status
		s = socket.socket()
		port = 12345 #connect to master multisensor port
		s.connect((MQTT_SERVER,port))

		if(pir.motion_detected==True):
			s.sendall(str(IPAddr) + "True")
		else:
			s.sendall(str(IPAddr) + "False")
		s.close()

	if(wordlist[0]=="Take"): #take photo and send it to main pi
		photoNum = int(wordlist[-1])
		path = '/home/pi/cameraTrapPhotos/set' + str(photoNum) + '/'
		access_rights = 0o777

        #make directory for current photo session
		try:
			os.mkdir(path,access_rights)
		except OSError:
			print("creation of the directory %s failed" % path)
		else:
			print("sucessfully created the directory %s" % path)

        #set up camera and file parameters
		photoName = 'set' + str(photoNum) + '_camera' + str(cameraNum) + '.jpg'
		camera.resolution = (3240,2464)
		camera.shutter_speed = 30000

        #take photo
		camera.capture(path + photoName)
		print("Photo Number " +  str(photoNum) +  " taken on Slave " + str(cameraNum))

		#FTP to master pi
		print("Moving from Cam "+ str(cameraNum) + " to Master")
		ftp = FTP(MQTT_SERVER)
		ftp.login('pi','raspberry')
		pathMaster = '/home/pi/cameraTrapPhotos/set' + str(photoNum) + '/'
		ftp.cwd(pathMaster)

		try:
			file = open(path + photoName,'rb')
		except OSError:
			print('could not open file')

		ftp.storbinary('STOR ' + pathMaster + photoName, file)
		print("Finished moving photo from Cam " + str(cameraNum) +" to master")
		file.close()
		ftp.quit()
        	print("closed FTP connection")

# Create an MQTT client and attach our routines to it.
client = mqtt.Client()
client.on_connect = on_connect
client.on_message = on_message

client.connect(MQTT_SERVER, 1883) #connect to mqtt server on master pi at port 1883, designated for MQTT protocol

# Process network traffic and dispatch callbacks. This will also handle
# reconnecting.
client.loop_forever()
